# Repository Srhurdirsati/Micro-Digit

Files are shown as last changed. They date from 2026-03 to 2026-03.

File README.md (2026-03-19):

# Micro Digit 

This project is my take on a keyboad; it is orthogonal keyboard with fancy knobs (cause who doesn't like knobs).
The reason I made this project is because I have never loved the keyboard I have had for years now, and I have always wanted to try an orthongonal keyboard. This keyboard is based on the creator keyboard by work louder but I am not paying $350 for a keyboard when I can just build one under $100

## Bill of Materials

Refer To bom.csv

## Images













## How To Set Up

No external wiring is needed, but you can check the schematic in the PCB folder above for more details.

-----------------------------------------------------------------

**Soldering**  

#### *As you have to hand solder all yourself , I would recommend to first solder the PICO on board, then the OLED display and then the keys .*

-----------------------------------------------------

**Firmware**

> Then By pressing boot button on the Pico , insert the able in it with other end on PC end

> Flash The .py firmware file in it .

> This would make the Pico know what it need to do.

---------------------------------------------

**Assembling**

> Now for completing the project , U'll need to assemble the CAD to finalise ther project

>  Start with putting the PCB in Base part .

> After that put the Top plate carefully ( Don't scratch PCB or OLED )

> Lock Everyting in place with M2 screws .

NOW EVERYTHING IS SET UP FINALLY AND THE PROJECT IS COMPLETE . 

` Total = $105 `

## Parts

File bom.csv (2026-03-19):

Name | Purpose | Cost Per Item (USD) | Quantity | Total (USD) | Link | Distributor
1'3'' Inch Display | Displaying | 5.00 | 1 | 5.00 | https://www.buydisplay.com/1-3-inch-tft-ips-lcd-display-module-240x240-spi-for-arduino-raspberry-pi | BuyDisplay
3D Print With Shipping | Main Structure | 10.00 | 1 | 10.00 | "-" | Printing Legion ( India )
KeyCaps | - | 15.00 | 1 | 15.00 | https://www.amazon.in/ETZIN-PBT-Mechanical-Universal-Compatiability/dp/B0BNKVHM7Q | Amazon
PCB | Main Circuit Board | 30.00 | 1 | 30.00 | https://cart.jlcpcb.com/ | JLCPCB
1n4148 | Just Diodes | 4.00 | 1 | 4.00 | https://www.amazon.in/100-Pieces-1N4148-Switching-High-Speed/dp/B079KJ91JZ | Amazon
482020514001 | (Encoder) | 10.00 | 1 | 10.00 | https://www.mouser.com/ProductDetail/Wurth-Elektronik/482020514001?qs=2WXlatMagcGAwM91AS9d8A%3D%3D | Mouser
Key Switches | Switches | 3.20 | 10 | 32.00 | https://meckeys.com/shop/accessories/keyboard-accessories/key-switches/kailh-box-v2-switches/ | meckeys
RPI Pico | Microcontrolller | 7.00 | 1 | 7.00 | https://amzn.in/d/0f7I34p2 | Amazon

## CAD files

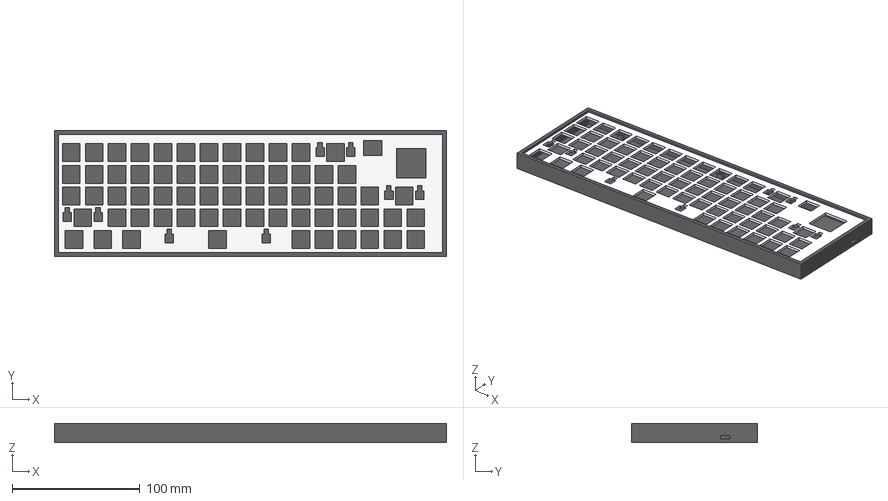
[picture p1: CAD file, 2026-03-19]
CAD/Assembly.step
307.2 x 98.4 x 14.9 mm
Linear Pattern 02

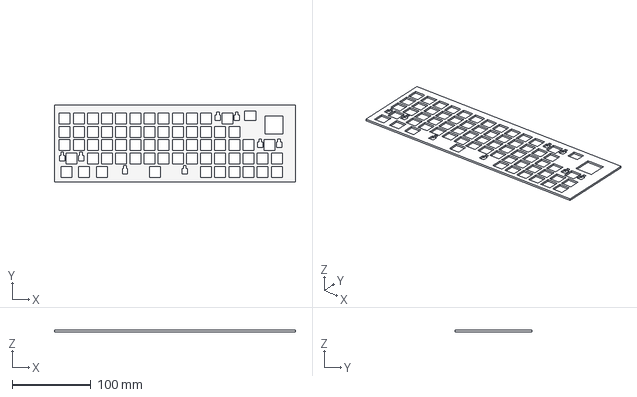
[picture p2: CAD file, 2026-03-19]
CAD/Top.step
306.7 x 97.9 x 2.20 mm

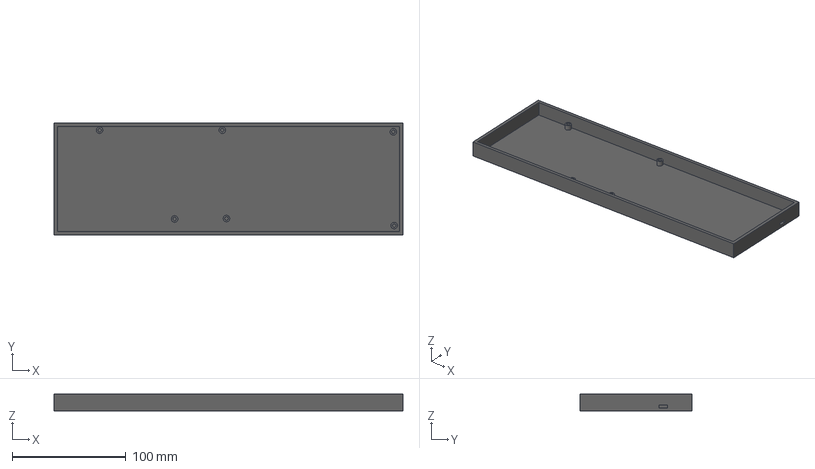
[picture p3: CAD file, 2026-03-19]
CAD/Bottom.step
307.2 x 98.4 x 14.9 mm
root
root001
root002
root003
root004
root005
root006

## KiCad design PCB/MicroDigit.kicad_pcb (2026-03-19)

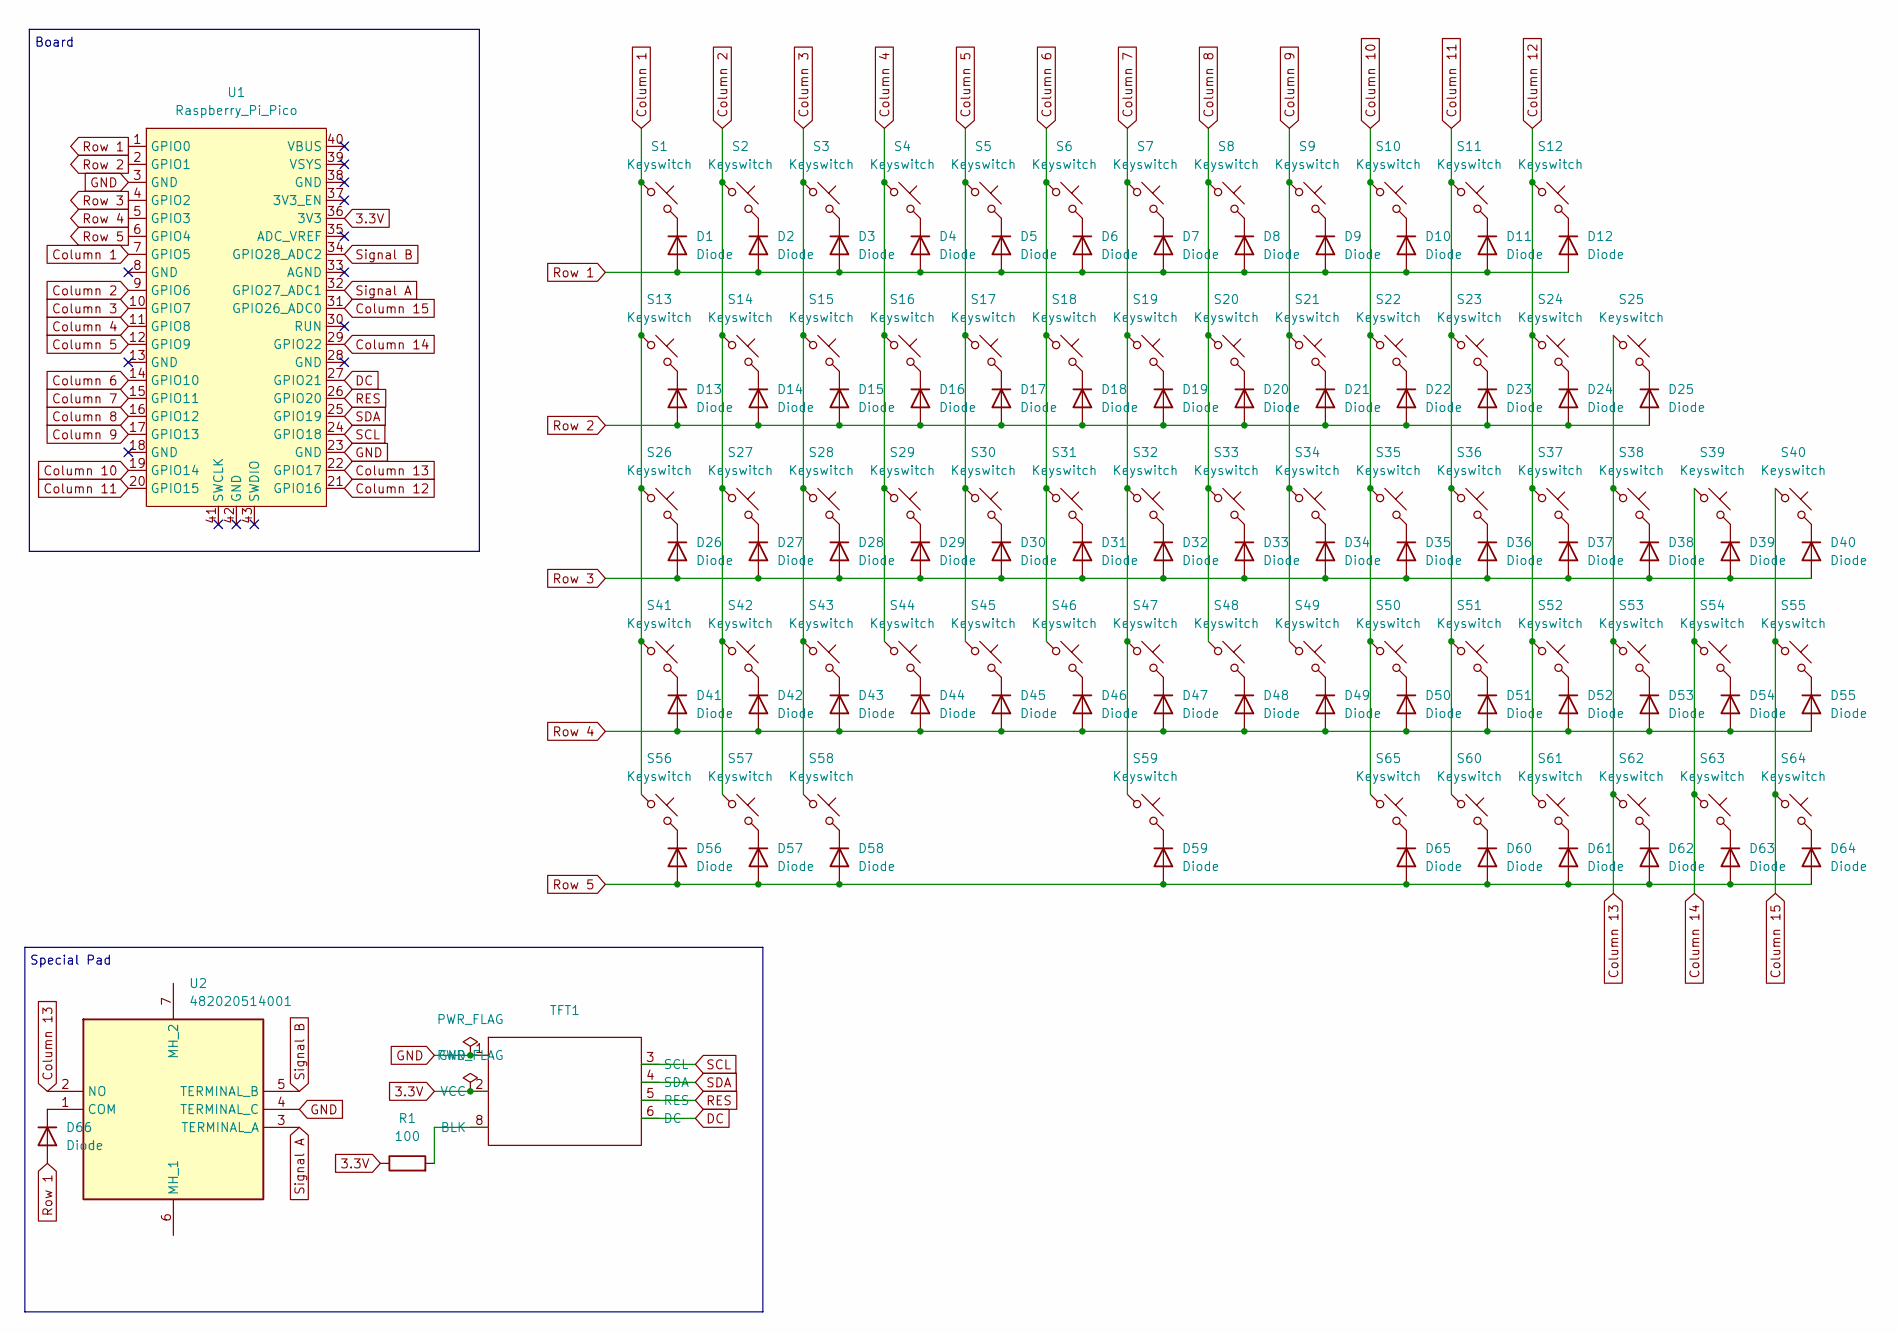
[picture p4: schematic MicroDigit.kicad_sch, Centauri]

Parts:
D1, D2, D3, D4, D5, D6, D7, D8, D9, D10, D11, D12, D13, D14, D15, D16, D17, D18, D19, D20, D21, D22, D23, D24, D25, D26, D27, D28, D29, D30, D31, D32, D33, D34, D35, D36, D37, D38, D39, D40, D41, D42, D43, D44, D45, D46, D47, D48, D49, D50, D51, D52, D53, D54, D55, D56, D57, D58, D59, D60, D61, D62, D63, D64, D65, D66: Diode; Diode_SOD-123
R1: 100; Resistor_0402
S1, S2, S3, S4, S5, S6, S7, S8, S9, S10, S11, S13, S14, S15, S16, S17, S18, S19, S20, S21, S22, S23, S24, S25, S26, S27, S28, S29, S30, S31, S32, S33, S34, S35, S36, S37, S38, S39, S42, S43, S44, S45, S46, S47, S48, S49, S50, S51, S52, S53, S54, S55, S60, S61, S62, S63, S64, S65: Keyswitch; Choc_V1_1.00u
S12, S40, S41: Keyswitch; Choc_V1_2.00u
S56, S57, S58: Keyswitch; Choc_V1_1.25u
S59: Keyswitch; Choc_V1_6.25u
TFT1: TFT_1.3_SPI_Module
U1: Raspberry_Pi_Pico; RaspberryPi_Pico_SMD_HandSolder
U2: 482020514001; Mouser Part Number 710-482020514001

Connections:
3.3V: R1.1, TFT1.2 (VCC), U1.36 (3V3)
Column 1: S1.1, S13.1, S26.1, S41.1, S56.1, U1.7 (GPIO5)
Column 2: S2.1, S14.1, S27.1, S42.1, S57.1, U1.9 (GPIO6)
Column 3: S3.1, S15.1, S28.1, S43.1, S58.1, U1.10 (GPIO7)
Column 4: S4.1, S16.1, S29.1, S44.1, U1.11 (GPIO8)
Column 5: S5.1, S17.1, S30.1, S45.1, U1.12 (GPIO9)
Column 6: S6.1, S18.1, S31.1, S46.1, U1.14 (GPIO10)
Column 7: S7.1, S19.1, S32.1, S47.1, S59.1, U1.15 (GPIO11)
Column 8: S8.1, S20.1, S33.1, S48.1, U1.16 (GPIO12)
Column 9: S9.1, S21.1, S34.1, S49.1, U1.17 (GPIO13)
Column 10: S10.1, S22.1, S35.1, S50.1, S65.1, U1.19 (GPIO14)
Column 11: S11.1, S23.1, S36.1, S51.1, S60.1, U1.20 (GPIO15)
Column 12: S12.1, S24.1, S37.1, S52.1, S61.1, U1.21 (GPIO16)
Column 13: S25.1, S38.1, S53.1, S62.1, U1.22 (GPIO17), U2.2 (NO)
Column 14: S39.1, S54.1, S63.1, U1.29 (GPIO22)
Column 15: S40.1, S55.1, S64.1, U1.31 (GPIO26_ADC0)
DC: TFT1.6 (DC), U1.27 (GPIO21)
GND: TFT1.1 (GND), U1.3 (GND), U1.23 (GND), U2.4 (TERMINAL_C)
unnamed: D1.1 (K), S1.2
unnamed: D2.1 (K), S2.2
unnamed: D3.1 (K), S3.2
unnamed: D4.1 (K), S4.2
unnamed: D5.1 (K), S5.2
unnamed: D6.1 (K), S6.2
unnamed: D7.1 (K), S7.2
unnamed: D8.1 (K), S8.2
unnamed: D9.1 (K), S9.2
unnamed: D10.1 (K), S10.2
unnamed: D11.1 (K), S11.2
unnamed: D12.1 (K), S12.2
unnamed: D13.1 (K), S13.2
unnamed: D14.1 (K), S14.2
unnamed: D15.1 (K), S15.2
unnamed: D16.1 (K), S16.2
unnamed: D17.1 (K), S17.2
unnamed: D18.1 (K), S18.2
unnamed: D19.1 (K), S19.2
unnamed: D20.1 (K), S20.2
unnamed: D21.1 (K), S21.2
unnamed: D22.1 (K), S22.2
unnamed: D23.1 (K), S23.2
unnamed: D24.1 (K), S24.2
unnamed: D25.1 (K), S25.2
unnamed: D26.1 (K), S26.2
unnamed: D27.1 (K), S27.2
unnamed: D28.1 (K), S28.2
unnamed: D29.1 (K), S29.2
unnamed: D30.1 (K), S30.2
unnamed: D31.1 (K), S31.2
unnamed: D32.1 (K), S32.2
unnamed: D33.1 (K), S33.2
unnamed: D34.1 (K), S34.2
unnamed: D35.1 (K), S35.2
unnamed: D36.1 (K), S36.2
unnamed: D37.1 (K), S37.2
unnamed: D38.1 (K), S38.2
unnamed: D39.1 (K), S39.2
unnamed: D40.1 (K), S40.2
unnamed: D41.1 (K), S41.2
unnamed: D42.1 (K), S42.2
unnamed: D43.1 (K), S43.2
unnamed: D44.1 (K), S44.2
unnamed: D45.1 (K), S45.2
unnamed: D46.1 (K), S46.2
unnamed: D47.1 (K), S47.2
unnamed: D48.1 (K), S48.2
unnamed: D49.1 (K), S49.2
unnamed: D50.1 (K), S50.2
unnamed: D51.1 (K), S51.2
unnamed: D52.1 (K), S52.2
unnamed: D53.1 (K), S53.2
unnamed: D54.1 (K), S54.2
unnamed: D55.1 (K), S55.2
unnamed: D56.1 (K), S56.2
unnamed: D57.1 (K), S57.2
unnamed: D58.1 (K), S58.2
unnamed: D59.1 (K), S59.2
unnamed: D60.1 (K), S60.2
unnamed: D61.1 (K), S61.2
unnamed: D62.1 (K), S62.2
unnamed: D63.1 (K), S63.2
unnamed: D64.1 (K), S64.2
unnamed: D65.1 (K), S65.2
unnamed: D66.1 (K), U2.1 (COM)
unnamed: R1.2, TFT1.8 (BLK)
RES: TFT1.5 (RES), U1.26 (GPIO20)
Row 1: D1.2 (A), D2.2 (A), D3.2 (A), D4.2 (A), D5.2 (A), D6.2 (A), D7.2 (A), D8.2 (A), D9.2 (A), D10.2 (A), D11.2 (A), D12.2 (A), D66.2 (A), U1.1 (GPIO0)
Row 2: D13.2 (A), D14.2 (A), D15.2 (A), D16.2 (A), D17.2 (A), D18.2 (A), D19.2 (A), D20.2 (A), D21.2 (A), D22.2 (A), D23.2 (A), D24.2 (A), D25.2 (A), U1.2 (GPIO1)
Row 3: D26.2 (A), D27.2 (A), D28.2 (A), D29.2 (A), D30.2 (A), D31.2 (A), D32.2 (A), D33.2 (A), D34.2 (A), D35.2 (A), D36.2 (A), D37.2 (A), D38.2 (A), D39.2 (A), D40.2 (A), U1.4 (GPIO2)
Row 4: D41.2 (A), D42.2 (A), D43.2 (A), D44.2 (A), D45.2 (A), D46.2 (A), D47.2 (A), D48.2 (A), D49.2 (A), D50.2 (A), D51.2 (A), D52.2 (A), D53.2 (A), D54.2 (A), D55.2 (A), U1.5 (GPIO3)
Row 5: D56.2 (A), D57.2 (A), D58.2 (A), D59.2 (A), D60.2 (A), D61.2 (A), D62.2 (A), D63.2 (A), D64.2 (A), D65.2 (A), U1.6 (GPIO4)
SCL: TFT1.3 (SCL), U1.24 (GPIO18)
SDA: TFT1.4 (SDA), U1.25 (GPIO19)
Signal A: U1.32 (GPIO27_ADC1), U2.3 (TERMINAL_A)
Signal B: U1.34 (GPIO28_ADC2), U2.5 (TERMINAL_B)

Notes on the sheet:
Special Pad
Board

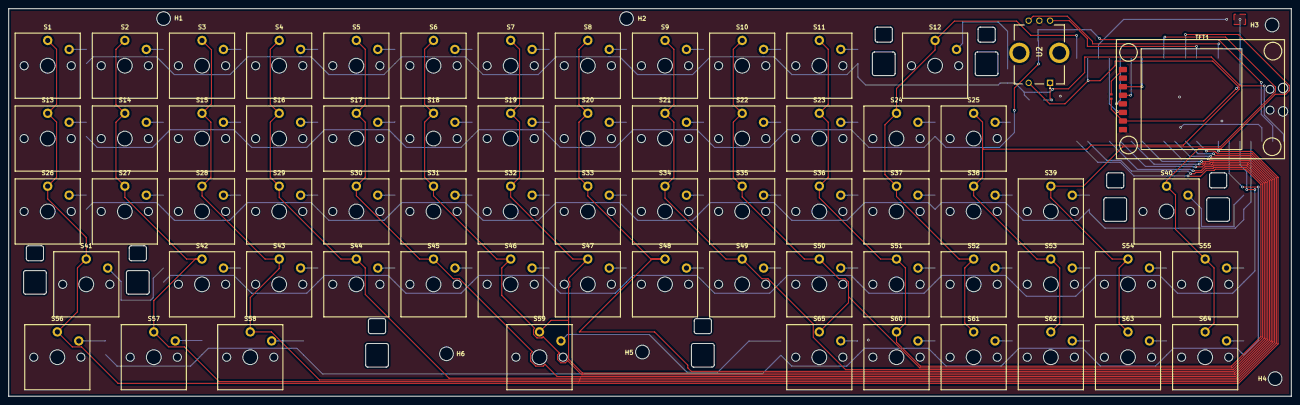
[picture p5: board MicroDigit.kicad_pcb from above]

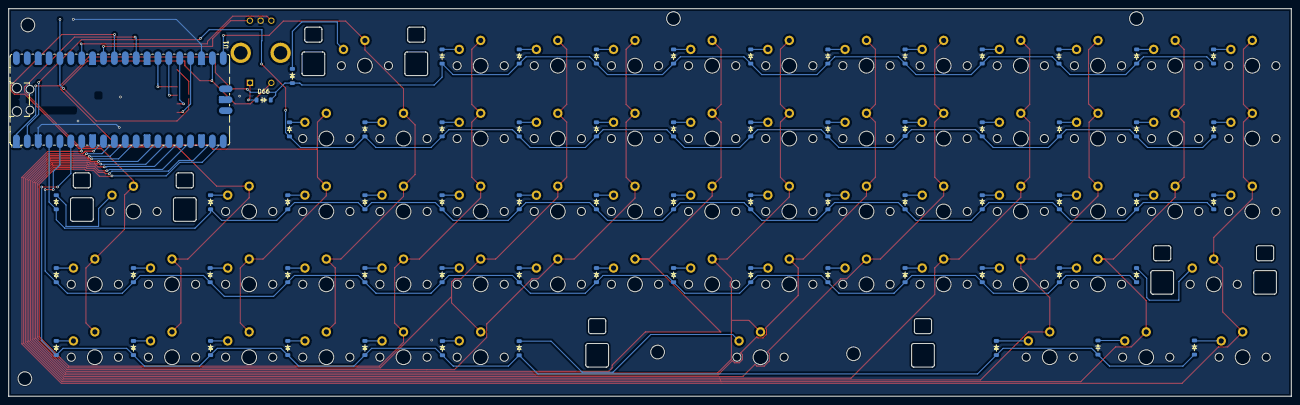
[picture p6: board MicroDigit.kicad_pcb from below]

Board: 2 copper layers, 299.2 x 90.4 mm, 141 parts (67 on the bottom side), 95 nets.

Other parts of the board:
H1, H2, H4, H5, H6: MountingHole; MountingHole_3.2mm_M3
H3: MountingHole_3.2mm_M3

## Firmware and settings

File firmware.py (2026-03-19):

import machine
import utime
import st7789

# --- Pin definitions ---
ROW_PINS = [machine.Pin(i, machine.Pin.OUT) for i in range(0, 5)]  # GPIO0-4
COL_PINS = [machine.Pin(i, machine.Pin.IN, machine.Pin.PULL_DOWN) for i in range(6, 17)]  # GPIO6-16

# TFT display pins
TFT_SCK = machine.Pin(18)
TFT_MOSI = machine.Pin(19)
TFT_DC = machine.Pin(20)
TFT_RES = machine.Pin(21)
TFT_CS = machine.Pin(22)
TFT_BL = machine.Pin(17, machine.Pin.OUT)

# Encoder pins
ENC_A = machine.Pin(26, machine.Pin.IN, machine.Pin.PULL_UP)
ENC_B = machine.Pin(27, machine.Pin.IN, machine.Pin.PULL_UP)
ENC_BTN = machine.Pin(28, machine.Pin.IN, machine.Pin.PULL_UP)

# --- TFT Setup ---
spi = machine.SPI(0, baudrate=40000000, sck=TFT_SCK, mosi=TFT_MOSI)
display = st7789.ST7789(
    spi, 240, 240,
    reset=TFT_RES,
    dc=TFT_DC,
    cs=TFT_CS,
    rotation=0
)
TFT_BL.value(1)
display.init()
display.fill(st7789.BLACK)

# --- Encoder state ---
encoder_value = 0
last_a = ENC_A.value()

# --- Caps Lock state ---
capslock = False
capslock_last = False
typed_text = ""

# --- Key mapping ---
KEY_MAP = {
    # Row 0 (top row)
    (0, 0): "ESC", (0, 1): "!", (0, 2): "1", (0, 3): "@", (0, 4): "2",
    (0, 5): "#", (0, 6): "3", (0, 7): "$", (0, 8): "4", (0, 9): "%", (0,10): "5",
    # Row 1
    (1, 0): "TAB", (1, 1): "=", (1, 2): "9", (1, 3): "W", (1, 4): "F",
    (1, 5): "P", (1, 6): "G", (1, 7): "J", (1, 8): "L", (1, 9): "U", (1,10): "Y",
    # Row 2
    (2, 0): "CAPS", (2, 1): "+", (2, 2): "A", (2, 3): "R", (2, 4): "S",
    (2, 5): "T", (2, 6): "N", (2, 7): "E", (2, 8): "I", (2, 9): "O", (2,10): "ENTER",
    # Row 3
    (3, 0): "SHIFT", (3, 1): "Z", (3, 2): "X", (3, 3): "C", (3, 4): "V",
    (3, 5): "B", (3, 6): "K", (3, 7): "M", (3, 8): "<", (3, 9): ">", (3,10): "?",
    # Row 4 (bottom row)
    (4, 0): "CTRL", (4, 1): "CMD", (4, 2): "ALT", (4, 3): "SPACE", (4, 4): "ALT",
    (4, 5): "FN", (4, 6): "LEFT", (4, 7): "DOWN", (4, 8): "UP", (4, 9): "RIGHT", (4,10): "BLANK",
}

def scan_matrix():
    pressed = []
    for row_idx, row in enumerate(ROW_PINS):
        for r in ROW_PINS:
            r.value(0)
        row.value(1)
        utime.sleep_us(50)
        for col_idx, col in enumerate(COL_PINS):
            if col.value():
                pressed.append((row_idx, col_idx))
    return pressed

def read_encoder():
    global encoder_value, last_a
    a = ENC_A.value()
    b = ENC_B.value()
    if a != last_a:
        if a == 1:
            if b == 0:
                encoder_value += 1
            else:
                encoder_value -= 1
    last_a = a

def show_status(keys, enc_val, capslock, text):
    display.fill(st7789.BLACK)
    display.text(
        st7789.FONT_Default, "Keys:", 10, 10, st7789.WHITE, st7789.BLACK
    )
    y = 30
    for k in keys:
        display.text(
            st7789.FONT_Default, f"R{k[0]} C{k[1]}", 10, y, st7789.YELLOW, st7789.BLACK
        )
        y += 20
    display.text(
        st7789.FONT_Default, f"Encoder: {enc_val}", 10, 200, st7789.CYAN, st7789.BLACK
    )
    display.text(
        st7789.FONT_Default, f"Btn: {'PRESSED' if ENC_BTN.value()==0 else 'UP'}", 10, 220, st7789.GREEN, st7789.BLACK
    )
    display.text(
        st7789.FONT_Default, f"Caps: {'ON' if capslock else 'OFF'}", 120, 10, st7789.RED if capslock else st7789.WHITE, st7789.BLACK
    )
    if text:
        display.text(
            st7789.FONT_Default, text, 10, 120, st7789.WHITE, st7789.BLACK
        )

# --- Main loop ---
while True:
    keys = scan_matrix()
    read_encoder()

    # Caps Lock logic
    capslock_pressed = (0, 0) in keys
    if capslock_pressed and not capslock_last:
        capslock = not capslock
    capslock_last = capslock_pressed

    # Add text if capslock is on and a mapped key is pressed (not CAPS key)
    if capslock:
        for k in keys:
            if k in KEY_MAP and KEY_MAP[k] != "CAPS":
                if len(typed_text) < 20:  # limit text length
                    typed_text += KEY_MAP[k]
                utime.sleep(0.2)  # simple debounce

    show_status(keys, encoder_value, capslock, typed_text)
    utime.sleep(0.1)

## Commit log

2026-03-19 Revise soldering and firmware instructions in README
    Updated instructions for soldering and firmware flashing.
2026-03-19 Fix entry for '3D Print With Shipping' in bom.csv
    [bom.csv]
